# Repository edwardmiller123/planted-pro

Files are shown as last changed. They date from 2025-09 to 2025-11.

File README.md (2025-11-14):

# planted-pro
This is the planted-pro plant monitor. It is my first electronics project and the goal was to create a full product end to end (mostly) from scratch. The repo aims to provide all the resources needed to build your very own if you so wished.

There is also the [planted-pro companion app](https://github.com/edwardmiller123/planted-pro-app)! Special thanks to [my wife](https://github.com/LucyRMCodes) for helping with this.

## Firmware
### Requirements
- [ARM GNU Toolchain](https://developer.arm.com/downloads/-/gnu-rm) - download the correct one for your system
- make
	- If on windows you can use a windows version like [Gnuwin32](https://gnuwin32.sourceforge.net/packages/make.htm)

- A device with the STLINK firmware. (For flashing main board) This could be an [official STlink debugger](https://uk.rs-online.com/web/p/debuggers-in-circuit-emulators/1827791) or a [nucleo board](https://www.st.com/en/evaluation-tools/nucleo-f446re.html)
- [OpenOCD](https://openocd.org/pages/getting-openocd.html) (For flashing main board)
	- [STLINK Tools](https://github.com/stlink-org/stlink) - Optional alternative
- gdb-multiarch (for flashing and debugging)

### Building
Compile the firmware with,
```
make fw
```

By default the fw is compiled without any log lines and with the debug LED on the main board disabled. To enable these simply run,
```
make fw LOGLEVEL={log level} (-B)
```
where {log level} ranges from 0 to 4 with 0 being FATAL and 4 being DEBUG. You may need to force a full rebuild with `-B` for make to pick up the symbol changes.

### Flashing The Board

## Main board
### Requirements
- [Kicad](https://www.kicad.org/)
- make
	- If on windows you can use a windows version like [Gnuwin32](https://gnuwin32.sourceforge.net/packages/make.htm)

### Exporting Fabrication Files
The gerber and drill files for the main board can be exported from kicad by running,
```
make pcb
```
This will create a `zip` of all the nessecary files ready to be sent to your favourite PCB manufacturer.

### Schematic
You can export a `pdf` of the schematic with,
```
make schematic
```

## Case
The case was designed in Tinkercad. STL files can be found in the `case` directory but you can also play with the original project online [here](https://www.tinkercad.com/things/aGYA4L6WpCP-planted-pro-v3).
Included in the `case` directory is a project file for [Bambu Studio](https://bambulab.com/en/download/studio) as I was printing on a [Bambu X1 Carbon](https://uk.store.bambulab.com/collections/x1-series) at [work](https://www.codethink.co.uk/). If using a different printer youll need to do the slicing yourself or you can send the `stl` files off to your favourite printing house.

## Constructing

### Requirements
- See previous sections for software requirements

You can generate all the nessecary files for contruction all at once by running,
```
make all
```

A full parts list can be found [here](docs/parts_list.md) in the docs folder along with data sheets for the MCU/ICs on the board and any external modules. 

# TODO
- Decrease the resistor values on the battery charge monitor to reduce noise

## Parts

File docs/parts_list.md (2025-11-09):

# Parts List
- Main board:
	- [STM32F446RC](https://lcsc.com/product-detail/Microcontrollers-MCU-MPU-SOC_STMicroelectronics-STM32F446RCT6_C915971.html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)
	- [Photo Resistor](https://lcsc.com/product-detail/Photoresistors_Senba-Sensing-Tech-GL5528_C125627.html?s_z=n_ldr)
	- [Potentiometer](https://www.lcsc.com/product-detail/C720648.html?s_z=n_potentiometer)
	- [Slide Switch](https://www.amazon.com/dp/B08SLPWDR9?ref_=ppx_hzod_title_dt_b_fed_asin_title_0_1&th=1)
	- [2mm JST Battery Connector](https://www.amazon.com/CQRobot-Pieces-Connector-Housing-Adapter/dp/B09DP9FZTX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)
	- buck converter:
		- [TLV62569DBV](https://www.lcsc.com/product-detail/DC-DC-Converters_Texas-Instruments-TLV62569DBVR_C141836.html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) (step down regulator) 
	- battery charging:
		- [MCP73831T](https://lcsc.com/product-detail/Battery-Management_Microchip-Tech-MCP73831T-2ACI-OT_C424093.html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) 
	- boost converter
		- [TPS613222A](https://www.lcsc.com/product-detail/C2071163.html?s_z=n_TPS613222A)
		- [Schottky Diode](https://www.lcsc.com/product-detail/C8678.html?s_z=n_Schottky%2520diode)
	- Capacitors (0603) (all 16v)
		- [22uF (x1)](https://www.lcsc.com/product-detail/C6119868.html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)
		- [4.7uF (x5)](https://lcsc.com/product-detail/Multilayer-Ceramic-Capacitors-MLCC-SMD-SMT_Samsung-Electro-Mechanics-CL10A475KO8NNNC_C19666.html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)
		- [10uF (x2)](https://lcsc.com/product-detail/Multilayer-Ceramic-Capacitors-MLCC-SMD-SMT_Samsung-Electro-Mechanics-CL10A106MO8NQNC_C92487.html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)
		- [100nF (x6)](https://lcsc.com/product-detail/Multilayer-Ceramic-Capacitors-MLCC-SMD-SMT_Samsung-Electro-Mechanics-CL10B104KO8NNNC_C66501.html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)
		- [120pF (x1)](https://www.lcsc.com/product-detail/C282671.html)
	- Resistors (0603)
		- [200k (x2)](https://lcsc.com/product-detail/Chip-Resistor-Surface-Mount_UNI-ROYAL-Uniroyal-Elec-0603WAF2003T5E_C25811.html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)
		- [2k (x1)](https://lcsc.com/product-detail/Chip-Resistor-Surface-Mount_FOJAN-FRC0603J202-TS_C2907137.html?s_z=n_resistors)
		- [1k (x1)](https://lcsc.com/product-detail/Chip-Resistor-Surface-Mount_UNI-ROYAL-Uniroyal-Elec-0603WAF1001T5E_C21190.html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)
		- [1.5k (x2)](https://lcsc.com/product-detail/Chip-Resistor-Surface-Mount_UNI-ROYAL-Uniroyal-Elec-0603WAF1501T5E_C22843.html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)
		- [450k (x1)](https://lcsc.com/product-detail/Chip-Resistor-Surface-Mount_UNI-ROYAL-Uniroyal-Elec-0603WAF4533T5E_C25818.html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)
		- [100k (x3)](https://www.lcsc.com/product-detail/C3016388.html)
		- [1 (x1)](https://www.lcsc.com/product-detail/C2907116.html)
		- [5 (x1)](https://www.lcsc.com/product-detail/C2933231.html)
	- Inductors:
		- [2.2uH 1A Inductor (x2)](https://www.lcsc.com/product-detail/C365953.html?s_z=n_inductors)
	- Resonance filter:
		- [Ferrite Bead](https://www.lcsc.com/product-detail/C79382.html) (30mΩ ±25% 120Ω@100MHz)
	- [USB-C Connector](https://lcsc.com/product-detail/USB-Connectors_SHOU-HAN-TYPE-C-6P-073_C668623.html?s_z=n_usb)

- External modules:
	- [HS1602A](https://lcsc.com/product-detail/LCD-Screen_HS-HS1602A-B_C18198249.html)
	- [Capacitive Moisture Sensor](https://thepihut.com/products/capacitive-soil-moisture-sensor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)
	- [Vollgo VG6328A Bluetooth module](https://www.lcsc.com/product-detail/C20539408.html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)

- [4.2v lipo Battery](https://www.adafruit.com/product/2011)

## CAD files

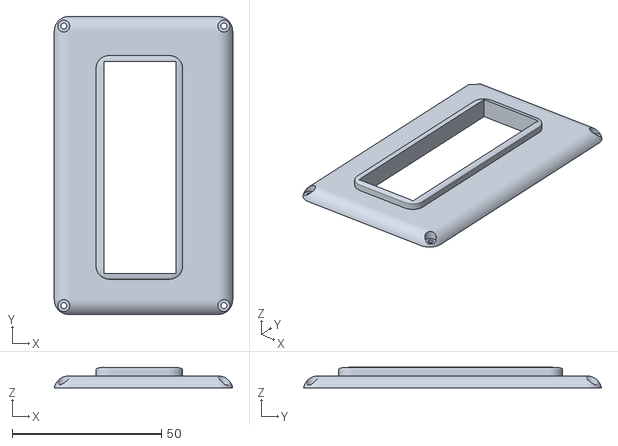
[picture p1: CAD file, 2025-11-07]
case/planted-pro-v3.5-lid.stl
59.8 x 99.8 x 6.92

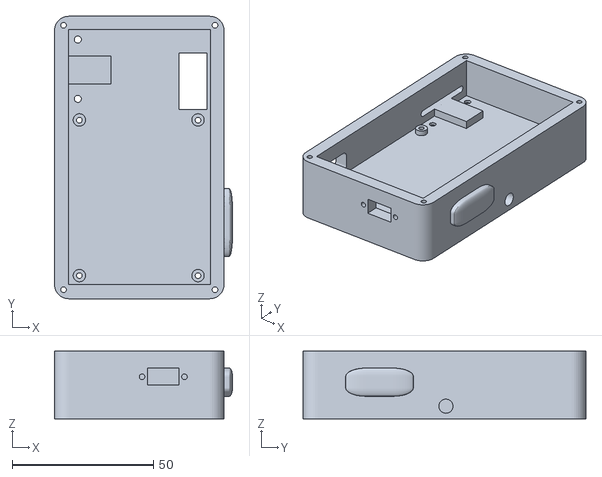
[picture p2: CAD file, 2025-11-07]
case/planted-pro-v3.5-body.stl
63.0 x 100.0 x 24.0

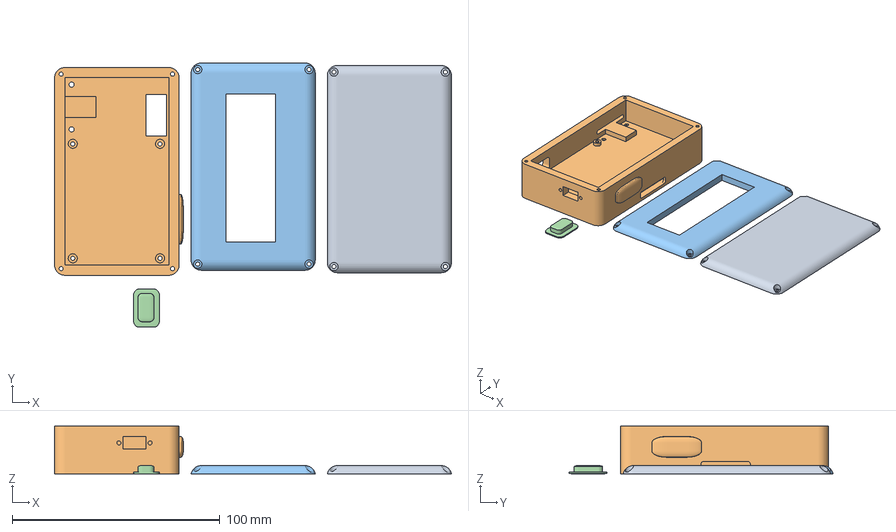
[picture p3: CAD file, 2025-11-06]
case/planted-pro-v3.3mf
191.0 x 127.1 x 23.0 mm
planted-pro-v3-bottom.stl
planted-pro-v3.4-body.stl
planted-pro-v3.4-lid.stl
planted-pro-v3.3-usb-cap.stl

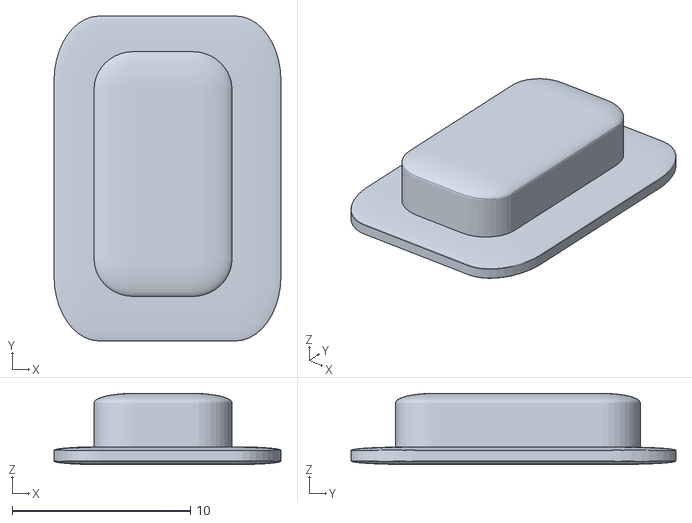
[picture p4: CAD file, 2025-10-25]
case/planted-pro-v3.3-usb-cap.stl
12.8 x 18.2 x 4.00

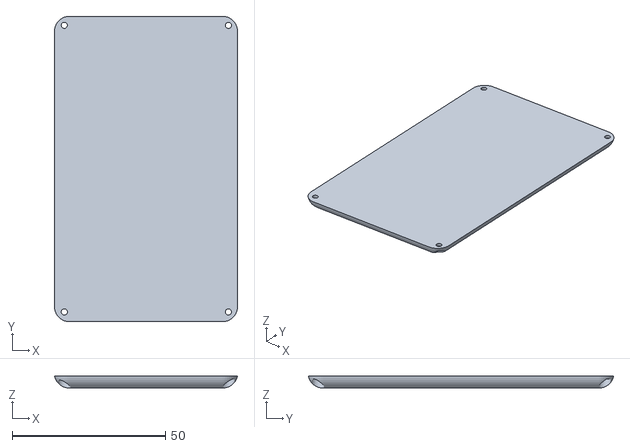
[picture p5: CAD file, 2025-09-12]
case/planted-pro-v3-bottom.stl
59.8 x 99.8 x 4.00

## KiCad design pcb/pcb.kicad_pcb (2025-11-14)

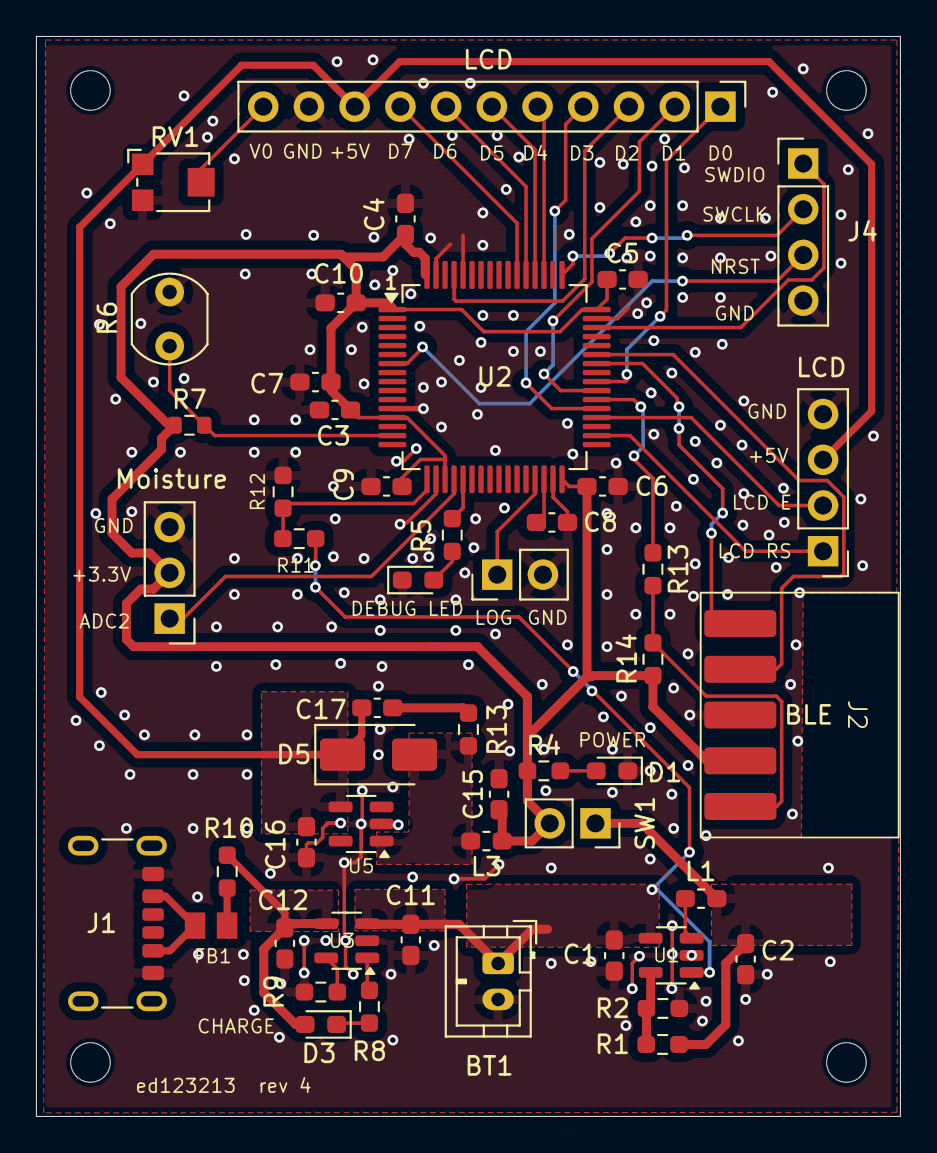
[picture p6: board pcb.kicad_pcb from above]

Board: 2 copper layers, 48.0 x 60.0 mm, 51 parts (0 on the bottom side), 41 nets.

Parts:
2.2mm: MountingHole_2.2mm_M2_ISO7380
BT1: 4.2v Lipo; JST_PH_B2B-PH-K_1x02_P2.00mm_Vertical
C1, C3, C8, C11, C12: 4.7uF; C_0603_1608Metric_Pad1.08x0.95mm_HandSolder
C2, C15: 10uF; C_0603_1608Metric_Pad1.08x0.95mm_HandSolder
C4, C5, C6, C7, C9, C10: 100nF; C_0603_1608Metric_Pad1.08x0.95mm_HandSolder
C16: 22uF; C_0603_1608Metric_Pad1.08x0.95mm_HandSolder
C17: 1nF; C_0603_1608Metric_Pad1.08x0.95mm_HandSolder
D1: PWR LED; LED_0603_1608Metric_Pad1.05x0.95mm_HandSolder
D2: DEBUG LED; LED_0603_1608Metric_Pad1.05x0.95mm_HandSolder
D3: CHARGE LED; LED_0603_1608Metric_Pad1.05x0.95mm_HandSolder
D5: SS38; D_SMA
FB1: FerriteBead; BEADC2012X105N
J1: USB_C_Receptacle_USB2.0_14P; USB_C_Receptacle_GCT_USB4125-xx-x-0190_6P_TopMnt_Horizontal
J2: LCD; PinHeader_1x11_P2.54mm_Vertical
J2#2: VG6328A; Vollgo VG6328A
J4: LCD CTRL; PinHeader_1x04_P2.54mm_Vertical
J4#2: Debug; PinHeader_1x04_P2.54mm_Vertical
J5: Moisture; PinHeader_1x03_P2.54mm_Vertical
J6: Logs; PinHeader_1x02_P2.54mm_Vertical
L1, L3: 2.2uH; L_0603_1608Metric_Pad1.05x0.95mm_HandSolder
R1: 453k; R_0603_1608Metric_Pad0.98x0.95mm_HandSolder
R2, R14: 100k; R_0603_1608Metric_Pad0.98x0.95mm_HandSolder
R4, R5: 1.5k; R_0603_1608Metric_Pad0.98x0.95mm_HandSolder
R6: LDR07; R_LDR_5.0x4.1mm_P3mm_Vertical
R7: 200k; R_0603_1608Metric
R8, R13: 1k; R_0603_1608Metric_Pad0.98x0.95mm_HandSolder
R9: 2k; R_0603_1608Metric_Pad0.98x0.95mm_HandSolder
R10: 1; R_0603_1608Metric_Pad0.98x0.95mm_HandSolder
R11, R12: 50k; R_0603_1608Metric_Pad0.98x0.95mm_HandSolder
R13#2: 10; R_0603_1608Metric_Pad0.98x0.95mm_HandSolder
RV1: LCD Contrast; Potentiometer_Bourns_TC33X_Vertical
SW1: PWR SWITCH; PinSocket_1x02_P2.54mm_Vertical
U1: TLV62569DBV; SOT-23-5
U2: STM32F446RETx; LQFP-64_10x10mm_P0.5mm
U3: MCP73831-2-OT; SOT-23-5
U5: TPS613222ADBV; SOT-23-5

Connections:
+3.3V: C3.1, C4.1, C5.1, C6.1, C7.1, C9.1, C10.1, C15.1, J2#2.4, J5.2, L3.1, R4.2, R7.1, R14.1, SW1.2 (B), U2.1 (VBAT), U2.13 (VDDA), U2.19 (VDD), U2.32 (VDD), U2.48 (VDD), U2.64 (VDD)
+3.3Vswin: C2.1, L1.2, R1.1, SW1.1 (A)
+5V: C16.1, C17.2, D5.1 (K), J2.9, J4.3, RV1.1, U5.4 (VOUT)
+Vbat: BT1.1 (+), C1.1, C11.1, R11.1, U1.1 (EN), U1.4 (VIN), U3.3 (V_{BAT})
+Vext: C12.1, D3.2 (A), R10.2, U3.4 (V_{DD})
ADC1: R6.1, R7.2, U2.15 (PA1)
ADC2: J5.1, U2.20 (PA4)
ADC3: R11.2, R12.1, U2.17 (PA3)
BT CONNECT: R13.1, U2.38 (PC7)
DEBUG LED: R5.2, U2.21 (PA5)
GND: BT1.2 (-), C1.2, C2.2, C3.2, C4.2, C5.2, C6.2, C7.2, C8.2, C9.2, C10.2, C11.2, C12.2, C15.2, C16.2, D1.1 (K), D2.1 (K), J1.A12 (GND), J1.B12 (GND), J2.10, J2#2.3, J4.4, J4#2.4, J5.3, J6.2, R2.2, R6.2, R9.2, R12.2, RV1.3, U1.2 (GND), U2.12 (VSSA), U2.18 (VSS), U2.31 (VSS), U2.47 (VSS), U2.60 (BOOT0), U2.63 (VSS), U3.2 (V_{SS}), U5.2 (GND)
LCD D1: J2.1, U2.40 (PC9)
LCD D2: J2.2, U2.39 (PC8)
LCD D3: J2.3, U2.61 (PB8)
LCD D4: J2.4, U2.37 (PC6)
LCD D5: J2.5, U2.51 (PC10)
LCD D6: J2.6, U2.52 (PC11)
LCD D7: J2.7, U2.53 (PC12)
LCD D8: J2.8, U2.54 (PD2)
LCD E: J4.2, U2.36 (PB15)
LCD RS: J4.1, U2.34 (PB13)
NRST: J4#2.3, U2.7 (NRST)
unnamed: C17.1, R13#2.2
unnamed: D1.2 (A), R4.1
unnamed: D2.2 (A), R5.1
unnamed: D3.1 (K), R8.1
unnamed: D5.2 (A), L3.2, R13#2.1, U5.1 (SW)
unnamed: FB1.1, J1.A9 (VBUS), J1.B9 (VBUS)
unnamed: FB1.2, R10.1
unnamed: J2#2.5, R13.2, R14.2
unnamed: J2.11, RV1.2
unnamed: R1.2, R2.1, U1.5 (FB)
unnamed: L1.1, U1.3 (SW)
unnamed: C8.1, U2.30 (VCAP_1)
unnamed: R9.1, U3.5 (PROG)
unnamed: R8.2, U3.1 (STAT)
SWCLK: J4#2.2, U2.49 (PA14)
SWDIO: J4#2.1, U2.46 (PA13)
USART1 RX: J2#2.2, U2.43 (PA10)
USART1 TX: J2#2.1, U2.42 (PA9)
USART3 TX: J6.1, U2.29 (PB10)

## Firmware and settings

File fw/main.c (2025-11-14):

#include <stdint.h>

#include "utils.h"
#include "interrupts.h"
#include "io.h"
#include "gpio.h"
#include "usart.h"
#include "time.h"
#include "logger.h"
#include "lcd.h"
#include "adc.h"
#include "sensor.h"
#include "heap.h"
#include "plantmonitor.h"

#include "interrupt_table.c"

int main(void)
{
    #ifdef LOGLEVEL
        set_log_level((log_level)LOGLEVEL);
    #endif

    // enable gpio ports A - D in AHB1 bus
    io_set_bit(RCC_AHB1ENR, 0);
    io_set_bit(RCC_AHB1ENR, 1);
    io_set_bit(RCC_AHB1ENR, 2);
    io_set_bit(RCC_AHB1ENR, 3);

    init_systick();

    init_debug_led();

    // used for logging
    configure_usart3(DEFAULT_BAUD);

    [[maybe_unused]] uint32_t args[1] = {get_system_counter()};
    LOGF(INFO, "Systick, LED2 and USART3 initialisation completed in $ ms", args, 1, NULL, 0);

    configure_lcd();

    configure_adc();

    // configured for the Volgo bluetooth module
    configure_usart1(BLUETOOTH_BAUD);
    LOG(INFO, "Initialised USART1");

    // if (configure_bluetooth() == -1) {
    //     LOG(ERROR, "Failed to configure bluetooth");
    //     init_fault_handler();
    // };

    init_heap();

    plant_monitor *pm = init_plant_monitor();
    if (pm == NULL)
    {
        init_fault_handler();
    }

    while (1)
    {
        run_monitor(pm);
    };

    return 0;
}

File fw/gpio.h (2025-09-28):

#ifndef LED_H
#define LED_H

#include <stdint.h>

#include "memmap.h"

typedef enum gpio {
	GPIOA,
	GPIOB,
	GPIOC,
	GPIOD
} gpio;

typedef enum gpio_action {
	CLEAR,
	SET
} gpio_action;

// alters the state the given pin in the given gpio port using the atomic BSSR register
void gpio_write_pin_atomic(gpio port, uint32_t pin, gpio_action action);

// GPIOA //

// base address of GPIOA port
#define GPIOA_BASE (AHB1_BASE + 0x0U)

#define GPIOA_MODER (GPIOA_BASE + 0x0U) // Output mode
#define GPIOA_OTYPER (GPIOA_BASE + 0x4U)
#define GPIOA_OSPEEDR (GPIOA_BASE + 0x8U)
#define GPIOA_PUPDR (GPIOA_BASE + 0x0CU)
#define GPIOA_AFRL (GPIOA_BASE + 0x20U) // Pin alternate functions 
#define GPIOA_AFRH (GPIOA_BASE + 0x24U) // Pin alternate functions 
#define GPIOA_ODR (GPIOA_BASE + 0x14U) // Output data register
#define GPIOA_BSSR (GPIOA_BASE + 0x18U) // Output data register

#define PA1 1
#define PA5 5

// GPIOB //

#define PB8 8
#define PB13 13
#define PB14 14
#define PB15 15

#define GPIOB_BASE (AHB1_BASE + 0x400U)

#define GPIOB_MODER (GPIOB_BASE + 0x0U)
#define GPIOB_OTYPER (GPIOB_BASE + 0x4U)
#define GPIOB_OSPEEDR (GPIOB_BASE + 0x8U)
#define GPIOB_PUPDR (GPIOB_BASE + 0x0CU)
#define GPIOB_AFRH (GPIOB_BASE + 0x24U)
#define GPIOB_ODR (GPIOB_BASE + 0x14U)
#define GPIOB_BSSR (GPIOB_BASE + 0x18U)

// GPIOC //

#define GPIOC_BASE (AHB1_BASE + 0x800U)

#define GPIOC_MODER (GPIOC_BASE + 0x0U)
#define GPIOC_OTYPER (GPIOC_BASE + 0x4U)
#define GPIOC_OSPEEDR (GPIOC_BASE + 0x8U)
#define GPIOC_PUPDR (GPIOC_BASE + 0x0CU)
#define GPIOC_AFRH (GPIOC_BASE + 0x24U)
#define GPIOC_ODR (GPIOC_BASE + 0x14U)
#define GPIOC_BSSR (GPIOC_BASE + 0x18U)

#define PC6 6
#define PC8 8
#define PC9 9
#define PC10 10
#define PC11 11
#define PC12 12

// GPIOD //

#define GPIOD_BASE (AHB1_BASE + 0xC00U)

#define GPIOD_MODER (GPIOD_BASE + 0x0U)
#define GPIOD_OTYPER (GPIOD_BASE + 0x4U)
#define GPIOD_OSPEEDR (GPIOD_BASE + 0x8U)
#define GPIOD_PUPDR (GPIOD_BASE + 0x0CU)
#define GPIOD_AFRH (GPIOD_BASE + 0x24U)
#define GPIOD_ODR (GPIOD_BASE + 0x14U)
#define GPIOD_BSSR (GPIOD_BASE + 0x18U)

#define PD2 2

// LED //

#define LED2 PA5

void toggle_debug_led();

void init_debug_led();

// Backup error signalling
void fast_blink();

#endif

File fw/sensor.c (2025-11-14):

#include <stdbool.h>
#include <stdint.h>

#include "utils.h"
#include "fpmath.h"
#include "logger.h"
#include "adc.h"
#include "sensor.h"
#include "heap.h"


sensor *init_sensor(uint32_t sample_size, adc adc_num)
{
	sensor *s = malloc(sizeof(sensor));
	if (s == NULL)
	{
		LOG(ERROR, "Failed to allocate memory for sensor");
		return NULL;
	}

	ring_buffer *readings = init_ring_buffer();
	if (readings == NULL)
	{
		LOG(ERROR, "Failed to initialise sensor readings buffer");
		return NULL;
	}

	s->readings_buffer = readings;

	s->sensor_percent = 0;
	s->sample_size = sample_size;
	s->adc_num = adc_num;
	return s;
}

int sensor_calculate_average(sensor *s)
{
	uint32_t total_val = 0;
	int32_t reading;
	for (int i = 0; i < s->sample_size; i++)
	{
		result_code read_result;
		reading = ring_buffer_read_word(s->readings_buffer, &read_result);
		if (read_result == EMPTY)
		{
			LOG(WARNING, "Sensor tried to read from empty readings buffer");
			return 0;
		}

		[[maybe_unused]] uint32_t args[] = {reading};
		LOGF(DEBUG, "Removed $ from sensor readings queue", args, 1, NULL, 0);

		total_val += reading;
	}

	uint32_t average = fp_divide(total_val, s->sample_size);
	s->raw_average = average;

	[[maybe_unused]] uint32_t args_average[] = {average};
	LOGF(DEBUG, "Set average sensor ADC value to $", args_average, 1, NULL, 0);

	return 0;
}

int sensor_read_adc(sensor *s)
{
	result_code adc_result;
	uint32_t reading = adc_manual_conversion(s->adc_num, &adc_result);
	if (adc_result == FAILURE)
	{
		LOG(ERROR, "Failed to read adc conversion");
		return -1;
	}

	ring_buffer_write_word(s->readings_buffer, reading);
	
	[[maybe_unused]] uint32_t args[] = {reading};
	LOGF(DEBUG, "Added $ to sensor readings buffer", args, 1, NULL, 0);
	return 0;
}

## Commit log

2025-04-14 add software reset and fix some logging issues
    [gpio.c, main.c]
2025-04-15 fix logger str concatenation
    [main.c]
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2025-05-09 fix light percentage calculation
    [main.c, monitor.c]
2025-05-25 start pcb schematic
    [pcb.kicad_pcb, pcb.kicad_sch]
2025-05-26 refactor and fix water percentage
    [main.c, monitor.c, plantmonitor.c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]
2025-05-26 add usart2 to schematic
    [pcb.kicad_sch]
2025-05-27 fix converter in schematic
    [pcb.kicad_sch]
2025-05-29 update schematic and readme
    [pcb.kicad_sch]
2025-05-31 better use of pins
    [pcb.kicad_sch]
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2025-06-14 fix json getting cut off
2025-06-15 fix bad water readings
    [plantmonitor.c]
2025-06-16 fix zeros not showing
    [plantmonitor.c]
2025-06-17 add battery charging circuit
    [pcb.kicad_sch]
2025-06-17 Add power and gnd pins for each component
    [pcb.kicad_sch]
2025-06-18 small schematic tweaks
    [pcb.kicad_sch]
2025-06-18 fix charging circuit resistor
    [pcb.kicad_sch]
2025-06-19 start designing pcb
    [pcb.kicad_pcb]
2025-06-20 arrange buck, charging circuit and f4
    [pcb.kicad_pcb]
2025-06-21 add capacitors to cpu
    [pcb.kicad_pcb]
2025-06-21 add pwr switch
    [pcb.kicad_pcb, pcb.kicad_sch]
2025-06-21 add traces for lcd rs re and hc-05
    [pcb.kicad_pcb]
2025-06-22 finish pcb
    [pcb.kicad_pcb, pcb.kicad_sch]
2025-06-23 move capacitors closer
    [pcb.kicad_pcb, pcb.kicad_sch]
2025-06-24 switch to grouped headers
    [pcb.kicad_pcb, pcb.kicad_sch]
2025-06-25 fix pcb errors
    [pcb.kicad_pcb]
2025-06-27 redesign charging circuit
    [pcb.kicad_pcb, pcb.kicad_sch]
2025-06-28 fix errors and add labels
    [pcb.kicad_pcb, pcb.kicad_sch]
2025-06-28 generate gerber files
    [pcb-B_Cu.gbl, pcb-B_Mask.gbs, pcb-B_Paste.gbp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]
2025-06-28 change name
    [pcb.kicad_pcb]
2025-06-29 fix drc errors and add mount holes
    [pcb-B_Cu.gbl, pcb-B_Mask.gbs, pcb-B_Paste.gbp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]
2025-06-29 export gerber files
    [pcb-B_Cu.gbl, pcb-B_Mask.gbs, pcb-B_Paste.gbp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]
2025-06-30 add vcap capacitor and widen traces
    [pcb-B_Cu.gbl, pcb-B_Mask.gbs, pcb-B_Paste.gbp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]
2025-06-30 increase board outline
    [pcb-B_Cu.gbl, pcb-B_Mask.gbs, pcb-B_Paste.gbp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]
2025-07-01 change design to use 0402 for buck converter
    [pcb.kicad_pcb, pcb.kicad_sch]
2025-07-01 change buck divider resistors
    [pcb-B_Cu.gbl, pcb-B_Mask.gbs, pcb-B_Paste.gbp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]
2025-07-06 replace queues with ring buffers
    [adc.c, main.c, monitor.c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]
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2025-07-19 add case stl files
    [Plant-monitor-body-v1.stl, Plant-monitor-v1-bottom.stl, Plant-monitor-v1-lid.stl]
2025-07-27 add lid window for charge led
    [Plant-monitor-v1-lid.stl]
2025-08-04 fix buck converter trace and add gerbers
    [pcb-B_Cu.gbl, pcb-B_Mask.gbs, pcb-B_Paste.gbp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]
2025-08-10 add taller case
    [Plant-monitor-body-v1.1.stl]
2025-08-13 start adding boost converter
    [lcd.kicad_sch, pcb.kicad_sch]
2025-08-15 add boost converter to schematic
    [lcd.kicad_sch, pcb.kicad_sch]
2025-08-15 redo case screw holes
    [Plant-monitor-body-v1.1.stl, Plant-monitor-body-v1.stl, Plant-monitor-v1-bottom.stl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]
2025-08-16 add boost converter voltage divider
    [lcd.kicad_sch, pcb.kicad_sch]
2025-08-19 re-do boost converter
    [lcd.kicad_sch]
2025-08-19 add footprints and update parts list
    [lcd.kicad_sch]
2025-08-19 start re-designing pcb
    [lcd.kicad_sch, pcb.kicad_pcb, pcb.kicad_sch]
2025-08-20 more pcb redesign
    [pcb.kicad_pcb]
2025-08-23 add resonance to schematic
    [pcb.kicad_pcb, pcb.kicad_sch]
2025-08-23 finish revision 2
    [pcb.kicad_pcb]
2025-08-26 add bambu project file for case
    [Plant-monitor-v1.3.3mf]
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2025-08-27 case v1.4
    [Plant-monitor-v1.3-body.stl, Plant-monitor-v1.3-bottom.stl, Plant-monitor-v1.3-lid.stl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]
2025-08-27 Add rev number to board
    [pcb.kicad_pcb]
2025-08-28 review notes and re slice case
    [Plant-monitor-v1.4.3mf]
2025-08-29 add power plane on boost converter input
    [pcb.kicad_pcb, pcb.kicad_sch]
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2025-08-29 mark pin 1 on stm32f4
    [pcb.kicad_pcb]
2025-09-01 redo bambu project file
    [Plant-monitor-v1.4.3mf]
2025-09-02 update bambu project and add review notes
    [Plant-monitor-v1.4-lid.stl, Plant-monitor-v1.4.3mf]
2025-09-02 add charge sensor to schematic
    [pcb.kicad_sch]
2025-09-03 Add battery sensor to pcb
    [pcb.kicad_pcb, pcb.kicad_sch]
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2025-09-05 Make power traces better on pcb
    [pcb.kicad_pcb]
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2025-09-08 Add pcb export to makefile
    [pcb-B_Cu.gbl, pcb-B_Mask.gbs, pcb-B_Paste.gbp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]
2025-09-09 update readme and makefile
    [pcb-B_Cu.gbl, pcb-B_Mask.gbs, pcb-B_Paste.gbp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]
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2025-09-09 Add more vias and input capacitor to schematic
    [pcb-B_Cu.gbl, pcb-B_Mask.gbs, pcb-B_Paste.gbp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]
2025-09-10 add input capacitor to boost converter
    [pcb-B_Cu.gbl, pcb-B_Mask.gbs, pcb-B_Paste.gbp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]
2025-09-10 Add volgo bluetooth module to pcb
    [pcb.kicad_pcb, pcb.kicad_sch]
2025-09-12 Improve volgo bluetooth footprint and add pull up for bt connect pin
    [pcb.kicad_pcb, pcb.kicad_sch]
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2025-09-15 move vias closer together
    [pcb.kicad_pcb]
2025-09-15 remove gnd plane under antenna correctly
    [pcb-B_Cu.gbl, pcb-B_Mask.gbs, pcb-B_Paste.gbp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]
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2025-09-21 make better space for antenna
    [planted-pro-v3-body.stl, planted-pro-v3.1-body.stl]
2025-09-21 add gnd sockets to debug headers
    [pcb-B_Cu.gbl, pcb-B_Mask.gbs, pcb-B_Paste.gbp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]
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2025-09-22 Add build directory to make file
    [pcb-B_Cu.gbl, pcb-B_Mask.gbs, pcb-B_Paste.gbp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]
2025-09-24 fix charge message not displaying
    [sensor.c]
2025-09-30 case design change notes
    [planted-pro-v3.3mf]
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2025-10-01 add case v 3.3 and more review notes
    [planted-pro-v3.1-lid.stl, planted-pro-v3.2-body.stl, planted-pro-v3.2-lid.stl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]
2025-10-03 Case changes: body-v3.4, usb-cap-v3.2, lid-v3.3
    [planted-pro-v3.1-usb-cap.stl, planted-pro-v3.2-lid.stl, planted-pro-v3.2-usb-cap.stl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]
2025-10-14 fix incorrect labels on schematic
    [pcb.kicad_pcb, pcb.kicad_sch]
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2025-10-21 Add lid v3.4 to 3d print project file
    [planted-pro-v3.3mf]
2025-10-24 set light levels based off percentages and fix water levels
    [monitor.c]
2025-10-25 add usb cap v3.3
    [planted-pro-v3.2-usb-cap.stl, planted-pro-v3.3-usb-cap.stl]
2025-11-06 Add usb-cap to bambu project file
    [planted-pro-v3.3mf]
2025-11-07 fix int overflow in ring buffer
    [plantmonitor.c]
2025-11-07 Add case lid and body v3.5
    [planted-pro-v3.4-body.stl, planted-pro-v3.4-lid.stl, planted-pro-v3.5-body.stl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]
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2025-11-14 change resistor values on bat monitor
    [pcb.kicad_pcb, pcb.kicad_sch]
